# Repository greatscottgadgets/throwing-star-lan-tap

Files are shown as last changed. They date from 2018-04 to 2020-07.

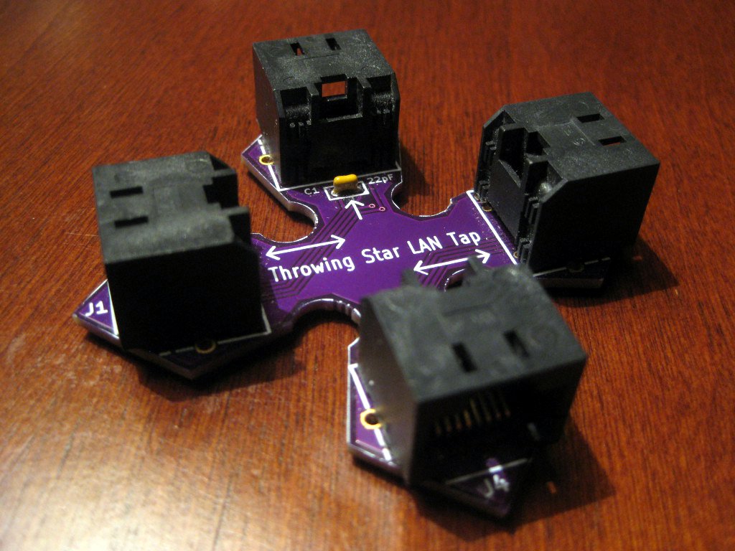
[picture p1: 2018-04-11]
assembly-photo.jpeg

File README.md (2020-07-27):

# Throwing Star LAN TAP

A passive tap for monitoring 10/100 Ethernet.

## parts required:
 * qty 4 RJ45 connectors: Amphenol RJHSE-5080 (unshielded) or RJHSE-5380 (shielded)
 * qty 2 220pF through-hole capacitors with .1" lead spacing (e.g. KEMET C315C221K1G5TA)

These design files are licensed under the terms in the file, LICENSE.

For more information: https://greatscottgadgets.com/throwingstar/

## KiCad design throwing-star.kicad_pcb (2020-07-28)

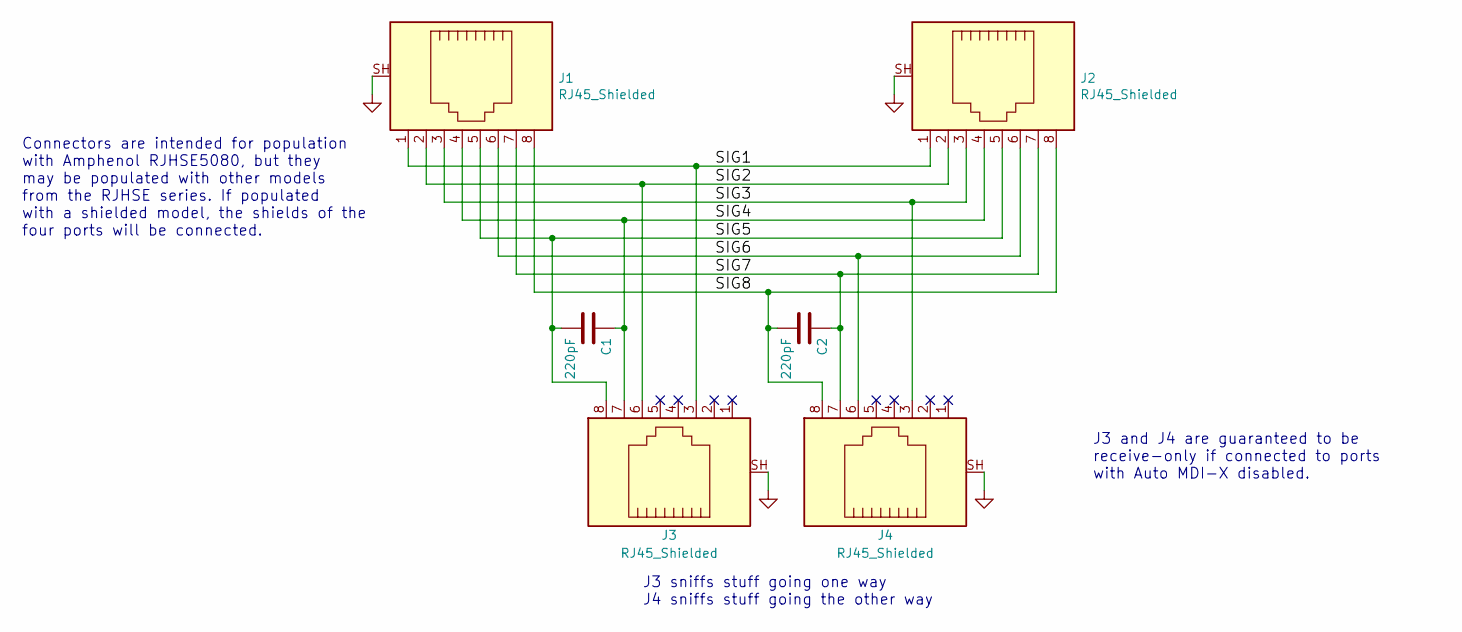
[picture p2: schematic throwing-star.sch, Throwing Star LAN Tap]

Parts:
C1, C2: 220pF; C_Disc_D5.0mm_W2.5mm_P2.50mm; Part Number C315C221K1G5TA
J1, J2, J3, J4: RJ45_Shielded; RJ45_Amphenol_RJHSE538X_TSLT; Part Number RJHSE5080

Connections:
/SIG1: J1.1, J2.1, J3.3
/SIG2: J1.2, J2.2, J3.6
/SIG3: J1.3, J2.3, J4.3
/SIG4: C1.1, J1.4, J2.4, J3.7
/SIG5: C1.2, J1.5, J2.5, J3.8
/SIG6: J1.6, J2.6, J4.6
/SIG7: C2.1, J1.7, J2.7, J4.7
/SIG8: C2.2, J1.8, J2.8, J4.8
GND: J1.SH, J2.SH, J3.SH, J4.SH

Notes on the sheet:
J3 sniffs stuff going one way J4 sniffs stuff going the other way
Connectors are intended for population with Amphenol RJHSE5080, but they may be populated with other models from the RJHSE series. If populated with a shielded model, the shields of the four ports will be connected.
J3 and J4 are guaranteed to be receive-only if connected to ports with Auto MDI-X disabled.

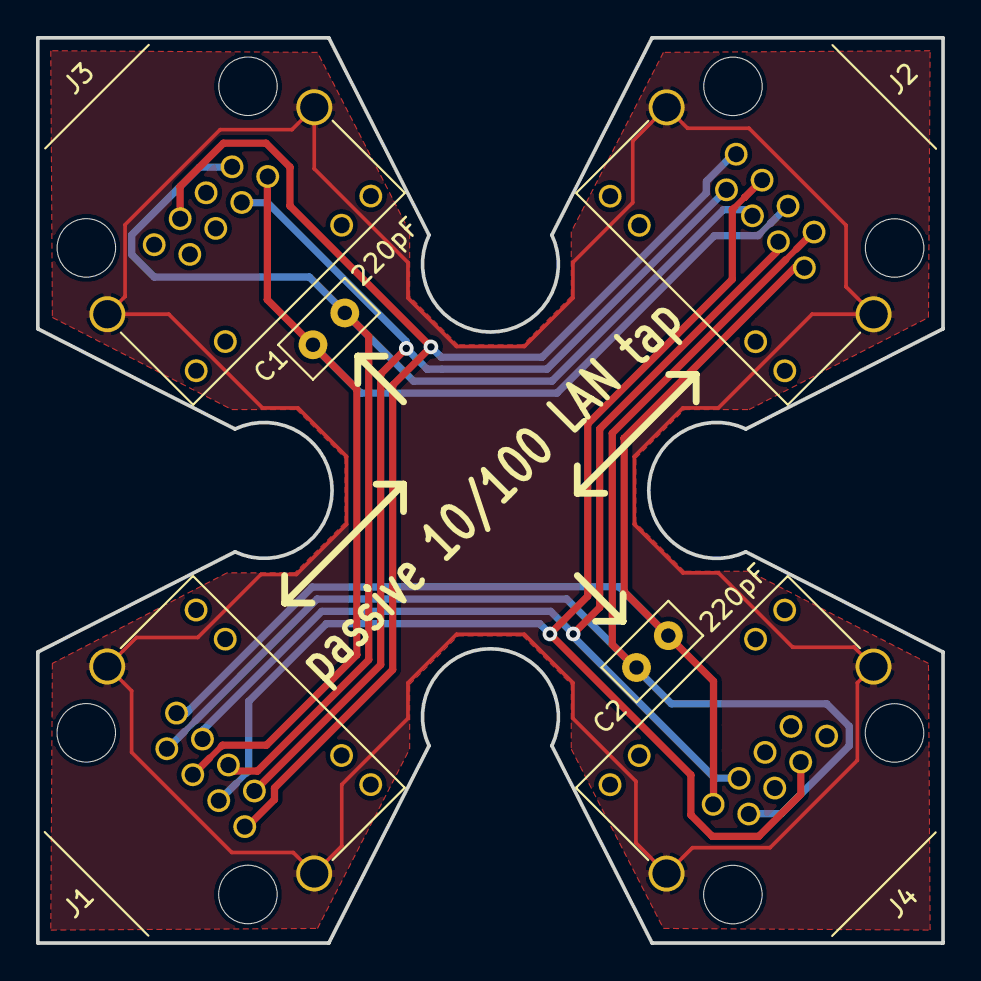
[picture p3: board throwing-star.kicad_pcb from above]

Board: 2 copper layers, 50.3 x 50.3 mm, 6 parts (0 on the bottom side), 9 nets.

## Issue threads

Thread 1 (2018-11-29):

Lan tap only works when monitor port is connected

mrockey19, 2018-11-29:
Hi,

I wanted to know if it was normal operation for the tap to only pass traffic on the J1 and J2 ports when one of the monitor ports is connected? For example, when a switch is connected to J1, and a computer to J2, the computer on J2 will show "No LAN cable connected" until a monitoring device is connected to J3.

Thanks,
Michael

mossmann, 2018-11-29:
No, that is not expected.  Do you have a cable plugged in to one or both of the monitor ports?  A dangling cable without a connection to a monitoring host can introduce a reflection that could result in a loss of communication.  This kind of problem is more likely when there are longer cables connected on J1 and/or J2.

mrockey19, 2018-11-29:
I think that was the issue. I was monitoring with a 25ft cable connected to 1 of the monitor ports. I was disconnecting the monitor host but not the monitor patch cable.

After your message I tried connecting J1 and J2 with no cable on the monitoring ports and it worked fine.

Thanks for the quick and helpful response.

Closed 2018-11-29.

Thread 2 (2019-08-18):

Throwing Star Mirror Port Mappings

KarelVenter, 2019-08-18:
Hi guys

I recently bought a Throwing Star Pro and need to understand which mirror ports maps to which source ports. Maybe I missed something but I cannot find this info on the website?

My assumption:
J3 = Tx feed from J1
J4 = Tx feed from J2

Would you please confirm?

Many thanks

MrMarioMichel, 2019-10-09:
Hope you figured it out already but for all others who are searching for the info.

# Usage

 1. Use Ethernet cables to connect the Throwing Star LAN Tap (J1 and J2) in line with a target network to be monitored.
2. Use Ethernet cables to connect one or both of the monitoring ports (J3 and J4) to ports on one or two monitoring stations. Each port monitors traffic in one direction only.
3. Use your favorite software (e.g., tcpdump or Wireshark) on the monitoring station(s) to capture network traffic.

http://greatscottgadgets.com/throwingstar/

mburr-precor, 2020-08-01:
According to the attached schematic (which was harder to find than I expected):

  - data transmitted by the J1 device shows up on J3
  - data transmitted by the J2 device shows up on J4

[throwing.star.lan.tap.schematic.pdf](https://github.com/greatscottgadgets/throwing-star-lan-tap/files/5009474/throwing.star.lan.tap.schematic.pdf)

KarelVenter, 2020-08-01:
Haha! This could not have been easy, it's literally been almost a year since my original query. Many many thanks. So, easy way to remember is that odd nrs map to odd (J1 to J3) and even to even (J2 to J4).

Closed 2020-08-01.

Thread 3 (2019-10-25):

Link LEDs should light up on target network ?

honza-1, 2019-10-25:
Hi,

I cannot make my LAN Tap Pro work. Additionally I would expect, when I connect a computer on J1 and a switch on J2 both on the target network, that on both sides the Link LEDs should light up/blink. Am I wrong. Is my Lan Tap damaged ?

Thankks fo advise.

Honza

miek, 2019-12-23:
The link LEDs should light on both ends (the same as if a single cable were connected between them).

It's worth making sure that both ends support 100BASETX and 10BASET as the LAN Tap will intentionally degrade the connection and force the link to be negotiated at a slower speed than usual. This may also change the behaviour of the link LEDs.

Also, make absolutely sure that the cables that you're testing with are good - ideally try some other ones in different combinations.

mossmann, 2021-01-23:
Are you still having trouble?  We will close this ticket in a month if we don't see a response.

straithe, 2021-02-23:
I'm going to close this as there hasn't been a response in a while, but please re-open this issue or open a new one if you still need assistance.

Closed 2021-02-23.

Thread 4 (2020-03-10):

PoE+ passthrough

Toontje, 2020-03-10:
Does this device support PoE(+) passthrough?

mossmann, 2021-01-23:
Yes. For more information, see: https://ossmann.blogspot.com/2011/11/power-over-ethernet-and-throwing-star.html

Closed 2021-01-23.

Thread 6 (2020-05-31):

No carrier on bottom tap link

rogerjames99, 2020-05-31:
I have had a Throwing Star lan tap for a number of years now but have not used it for some time. I have two rtl8169 pci ethernet adapters connected to the two. No matter what combination of cables and adapters I use I cannot get any carrier detected on the lower tap  interface (viewed with the legend "Throwing Star Lan Tap" on the pcb the the right way up). I have also tried this with a recently purchased Pro version with the same results. Do you have any ideas on what may be causing this? Have you had any reports of rtl8169 based adaptors causing problems. Could this be anything to do with MDI-X.

miek, 2020-05-31:
If you swap the left and right connections, does the problem stay on the bottom tap or move to the top?

rogerjames99, 2020-06-01:
Stays on the bottom.

Also tested the the lower tap with a usb adapter based on the  rtl8153 chip. Same result. I remember that some time ago I go the original tap working on a different piece of kit by using a pair of crossover cables one for each tap.

I am really scratching my head on this one. This isnt anything in these things to go wrong.

I have just noticed that the carrier goes off on the through link when the bottom cable is plugged in. I will find or make some nice short cables and see what happens.

mossmann, 2021-01-23:
I think you could be right about it being related to MDI/MDI-X. Here are some things you could try: Use the shortest cables you can (especially on the monitor ports). Try a crossover cable only on the failing port. Manually set all monitoring and target interfaces to 100BASE-TX.

straithe, 2021-02-23:
I'm going to close this as is looks like this issue has been solved. Please re-open this issue or open a new one if you still need assistance.

Closed 2021-02-23.

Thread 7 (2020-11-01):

No packets on router

thorag76, 2020-11-01:
I am able to capture packets on the LAN this works perfectly. But I was also hoping to be able to capture packets on the DSL interface of a Fritz!Box, which is a WAN port. With the device looped in the DSL connection, the connection can still be established successfully but I don't see any packets on either of the side jacks. The DSL RJ45 plug only  has 2 wires (the ones in the  middle).

mossmann, 2021-01-24:
Throwing Star LAN Tap was definitely not designed for DSL, but there is some potential that you could figure out a way to do what you want. The middle two wires (pins 4 and 5) on connectors J1 and J2 connect to pins 7 and 8 on connector J3. They do not connect to J4. If you were to crimp your own cable, you could connect this pair on J3 to a monitoring device. I have no idea if any DSL devices support a monitoring mode, but maybe this will get you started!

straithe, 2021-02-23:
I'm going to close this as it looks like this issue has been solved. Please re-open this issue or open a new one if you still need assistance.

Closed 2021-02-23.

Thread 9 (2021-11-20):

J1<->J2 traffic stops when connecting a cable to J4

yanshay, 2021-11-20:
I bought Throwing Star Lan Tap on Amazon.

I connect the traffic cables to J1 and J2, and communication works fine with only those connected.

Once I connect a cable to J4 communication between J1 and J2 hangs. It hangs when just connecting a cable with nothing connected to its other end. I checked this with several different cables that all are working fine.
If I connect it to a machine with wireshark, I can see packets on J4 at that time.

If I connect a cable to J3 communication sometimes hangs up but not always.
And if I try to capture with wireshark then I don't see any traffic.

Any ideas what could cause this behavior?
Is that a faulty lan tap I received?

Thanks

gozu42, 2021-11-20:
can you please post the output of ethtool on one (or even better both) sides of the link in both working and not working situation?
how long are the involved cables?

yanshay, 2021-11-20:
One side (J2) is a switch so I can run only on the other side (J1) (rasbperry pi).

Below is ethtool output with no cable connected, with cable connected on J4 and with cable connected on J3

--- With No Cable Connected ---
Settings for eth0:
	Supported ports: [ TP MII ]
	Supported link modes:   10baseT/Half 10baseT/Full
	                        100baseT/Half 100baseT/Full
	                        1000baseT/Half 1000baseT/Full
	Supported pause frame use: Symmetric Receive-only
	Supports auto-negotiation: Yes
	Supported FEC modes: Not reported
	Advertised link modes:  10baseT/Half 10baseT/Full
	                        100baseT/Half 100baseT/Full
	                        1000baseT/Half 1000baseT/Full
	Advertised pause frame use: Symmetric Receive-only
	Advertised auto-negotiation: Yes
	Advertised FEC modes: Not reported
	Link partner advertised link modes:  10baseT/Half 10baseT/Full
	                                     100baseT/Half 100baseT/Full
	Link partner advertised pause frame use: Symmetric Receive-only
	Link partner advertised auto-negotiation: Yes
	Link partner advertised FEC modes: Not reported
	Speed: 100Mb/s
	Duplex: Full
	Port: Twisted Pair
	PHYAD: 1
	Transceiver: internal
	Auto-negotiation: on
	MDI-X: Unknown
	Supports Wake-on: gsf
	Wake-on: d
        SecureOn password: 00:00:00:00:00:00
	Current message level: 0x00000007 (7)
			       drv probe link
	Link detected: yes

--- With cable connected to J4 ---
Settings for eth0:
	Supported ports: [ TP MII ]
	Supported link modes:   10baseT/Half 10baseT/Full
	                        100baseT/Half 100baseT/Full
	                        1000baseT/Half 1000baseT/Full
	Supported pause frame use: Symmetric Receive-only
	Supports auto-negotiation: Yes
	Supported FEC modes: Not reported
	Advertised link modes:  10baseT/Half 10baseT/Full
	                        100baseT/Half 100baseT/Full
	                        1000baseT/Half 1000baseT/Full
	Advertised pause frame use: Symmetric Receive-only
	Advertised auto-negotiation: Yes
	Advertised FEC modes: Not reported
	Speed: Unknown!
	Duplex: Unknown! (255)
	Port: Twisted Pair
	PHYAD: 1
	Transceiver: internal
	Auto-negotiation: on
	MDI-X: Unknown
	Supports Wake-on: gsf
	Wake-on: d
        SecureOn password: 00:00:00:00:00:00
	Current message level: 0x00000007 (7)
			       drv probe link
	Link detected: no

--- With cable connected on J3 (and now this didn't cause a network disconnect, also ethtool seems to show the same as w/o cable connected but I still post the output) ---

Settings for eth0:
	Supported ports: [ TP MII ]
	Supported link modes:   10baseT/Half 10baseT/Full
	                        100baseT/Half 100baseT/Full
	                        1000baseT/Half 1000baseT/Full
	Supported pause frame use: Symmetric Receive-only
	Supports auto-negotiation: Yes
	Supported FEC modes: Not reported
	Advertised link modes:  10baseT/Half 10baseT/Full
	                        100baseT/Half 100baseT/Full
	                        1000baseT/Half 1000baseT/Full
	Advertised pause frame use: Symmetric Receive-only
	Advertised auto-negotiation: Yes
	Advertised FEC modes: Not reported
	Link partner advertised link modes:  10baseT/Half 10baseT/Full
	                                     100baseT/Half 100baseT/Full
	Link partner advertised pause frame use: Symmetric Receive-only
	Link partner advertised auto-negotiation: Yes
	Link partner advertised FEC modes: Not reported
	Speed: 100Mb/s
	Duplex: Full
	Port: Twisted Pair
	PHYAD: 1
	Transceiver: internal
	Auto-negotiation: on
	MDI-X: Unknown
	Supports Wake-on: gsf
	Wake-on: d
        SecureOn password: 00:00:00:00:00:00
	Current message level: 0x00000007 (7)
			       drv probe link
	Link detected: yes

yanshay, 2021-11-20:
Oh, forgot to answer on the cables length, not long ones - around 1 meter ( I tried also with a longer cable around 6m and same behavior)

yanshay, 2021-11-21:
I found a way to workaround the issue for now - I used two 100mbps switches (so such that don't support 1Gbps) between the switch and the raspberry PI and also used short cables and that allowed me to do the traffic sniffing. Pretty cumbersome but worked.

straithe, 2021-11-29:
I'm happy to hear you found a solution, and I'm sorry I didn't get back to you sooner (I was on vacation). Are you happy with your solution, or would you like more support?

yanshay, 2021-11-30:
My solution is very cumbersome and actually made me think I should purchase a managed switch for a more acceptable usage. If there's a way to solve this it would be great but seems to me it's caused by some specific equipment I'm using with which this device doesn't work.

gozu42, 2021-11-30:
> My solution is very cumbersome and actually made me think I should purchase a managed switch for a more acceptable usage.

i can recommend the netgear GS108T series switches as sniffing adapters. compact, no fan, 1Gbps, port mirroring. (also vlans, multicast, and a lot of other premium/managed features)

> If there's a way to solve this it would be great but seems to me it's caused by some specific equipment I'm using with which this device doesn't work.

an issue common to all "passive" sniffing adapters. they do horrible things to the signal quality/path (by design), so its always possible to get unlucky and have it push more sensitive devices "over the edge" into not working.

yanshay, 2021-11-30:
> i can recommend the netgear GS108T series switches as sniffing adapters. compact, no fan, 1Gbps, port mirroring. (also vlans, multicast, and a lot of other premium/managed features)
I was actually thinking about TP-Link TL-SG108E which I found much cheaper at Amazon, any difference between the two?

mossmann, 2021-12-08:
> Once I connect a cable to J4 communication between J1 and J2 hangs. It hangs when just connecting a cable with nothing connected to its other end.

Have you tried plugging in the other end of the cable before connecting it to J4 (or J3)? Unterminated cables connected to the monitoring ports can introduce reflections that cause problems with communications on the target network segment.

straithe, 2022-01-28:
I'm going to close this as there hasn't been a response in a while, but please re-open this issue or open a new one if you still need assistance.

Closed 2022-01-28.

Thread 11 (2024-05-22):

Lan tap switches off when two interfaces connected

ricamz, 2024-05-22:
Hi there.

I have a throwing star lan tap pro, already assembled.

When I connect the two monitoring interfaces (J3 and J4) to any device (even separate devices) , the network ports where the monitoring interfaces are connected switches off, although the traffic apparently continues to pass through. Why does that happen?

The clarify I will do a step by step:

1. connect the throwing star lan tap pro pass through interfaces J1 and J2 in the network and everything works fine.
2. connect one monitoring interface (J3 or J4) to switch and i can sniff traffic only in one direction
3. connect the other monitoring interface to different computer and both monitoring interfaces switch off

Now I just have one monitoring interface connected.

What could be the reason of this and how can I solve it? Is it a faulty lan tap?

Regards

RS

straithe, 2024-06-13:
Can you please provide a picture of your set up? That would really help in diagnosing your issue.

ricamz, 2024-06-16:
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

Above is the drawing. When I connect the red line (from J4 to the switch) the throwing star J3 and J4 switches off. J1 and J2 continues to operate.

I even tried to connect the J3 and J4 to different switches (due to possible spanning tree of the switch) but same behaviour.

mossmann, 2024-06-26:
It is unusual to connect the monitor ports to a switch. I would expect that to work only with certain switch models and only when their ports are configured for promiscuous mirroring.

Does this happen if you connect J3 and J4 to promiscuous-mode host ports instead of to a switch?

ricamz, 2024-06-27:
Hi Mossmann.

I didn't connect J3 and J4 to a promiscuous-mode host ports. What I did is connect J3 to a switch and J4 to a promiscuous-mode host ports and the behaviour was J3 and J4 went shutdown.

By connecting J3 and J4 to a promiscuous-mode host ports you would need two network interfaces in the host, and I don't have that. I just have one network interface left.

Didn't you use old network hubs to connect J3 and J4?

Ricardo

mossmann, 2024-06-27:
TSLT is a passive tap. Ports J3 and J4 are wired directly to J1 and J2. There is no way for a TSLT to shut down or switch off a port. If you are seeing traffic stop completely on J3 or J4, it is likely because of behavior of the device connected to the port, not because of any behavior of the TSLT.

mossmann, 2024-06-27:
I do not think there is anything wrong with your TSLT. I recommend connecting both J3 and J4 to two promiscuous-mode host ports. The two ports need not be on the same host.

ricamz, 2024-06-27:
Thank you for the explanation. It is strange what is happening, but I will try connecting to two host ports to see what happens. I continues, I will re-open this thread.

But the strangest thing was that if I connect on a switch and to a host port (in promisc.) both J3 and J4 switch off.

mossmann, 2024-06-27:
I agree that is strange. Are you certain that J1 and J2 are operating normally with successful communication in both directions when traffic stops on J3 and J4?

ricamz, 2024-06-27:
I think so, because it is a firewall that serves many requests and if it fails for a bit I would have some complain and I didn't had any. But I haven't done any test to be sure.

Furthermore, if I disconnect J3 and J4, wait a bit and connect J3 alone (or J4 alone) I can monitor the traffic in one direction.

Closed 2024-06-27.

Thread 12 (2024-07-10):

Traffic between J1/J2 only works in one orientation

mattgio22, 2024-07-10:
Hello - I purchased the fully assembled Throwing Star LAN Tap Pro a while back, but only just started using it. I have been able to monitor traffic on J3 if I plug my switch into J1 and computer into J2 - in that configuration I cannot monitor any traffic on J4. However, if I plug my computer into J1 and switch into J2, the connection between computer and switch fails, and I cannot monitor traffic either. I am using 1-2ft cables.

Forgive me if this is a simple problem, but I'd appreciate any help! Thanks

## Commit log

2018-04-11 Initial commit of TSLT design files from 2011 tar archive
    [throwing-star.brd, throwing-star.sch]
2020-07-27 update design to KiCad 5.1
    [throwing-star.brd, throwing-star.kicad_pcb, throwing-star.sch]
2020-07-27 update license to CERN-OHL-P v2
    [throwing-star.kicad_pcb, throwing-star.sch]
2020-07-28 add Throwing Star LAN Tap Pro layout
    [throwing-star-pro.kicad_pcb, throwing-star.kicad_pcb, throwing-star.sch]

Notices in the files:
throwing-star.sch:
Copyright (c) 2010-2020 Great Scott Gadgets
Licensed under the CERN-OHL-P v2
